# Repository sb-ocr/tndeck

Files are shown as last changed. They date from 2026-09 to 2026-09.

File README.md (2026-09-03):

# TN Deck

Watch the build video ↓

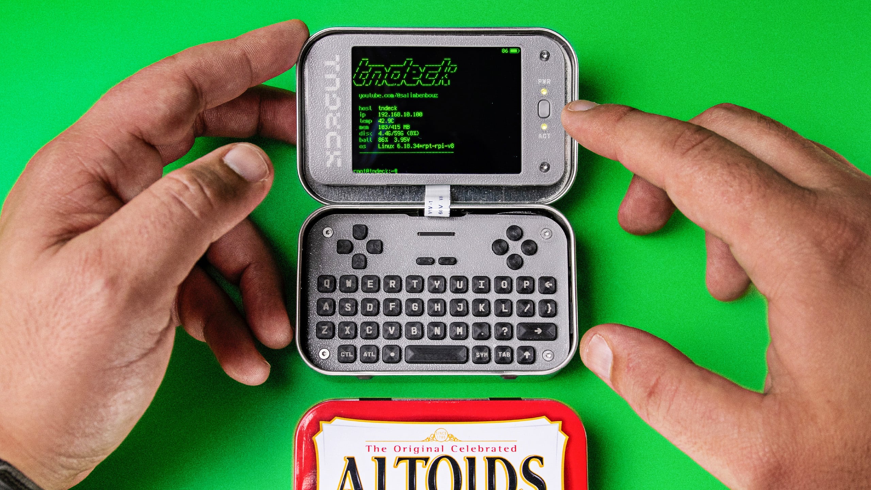
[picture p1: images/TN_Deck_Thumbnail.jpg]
[](https://youtu.be/Ajft97gAxV8)

TN Deck is a tiny handheld cyberdeck built inside an Altoids tin around the Raspberry Pi Compute Module 0. Inspired by projects like the MintyPi and other tin-based builds, it uses custom PCBs, an integrated keyboard, a small display, onboard audio, and battery power.

<sub>⚠️ In these files, R23 was changed to 2.2kΩ to fix the soft-latch issue, and C33 was added to help reset the audio DAC on power-up.</sub>

[][cc-by-nc-sa]

[][cc-by-nc-sa]

[cc-by-nc-sa]: http://creativecommons.org/licenses/by-nc-sa/4.0/
[cc-by-nc-sa-image]: https://licensebuttons.net/l/by-nc-sa/4.0/88x31.png
[cc-by-nc-sa-shield]: https://img.shields.io/badge/License-CC%20BY--NC--SA%204.0-lightgrey.svg

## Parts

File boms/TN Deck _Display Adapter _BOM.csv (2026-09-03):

Reference Designators | Quantity | Package | Value | Vendor Part Number | Vendor | Description | Manufacturer | Manufacturer Part Number | Top/Bottom
 | 1 | Board |  |  |  | Board
C2, C31 | 2 | CAPC1608X85 | 0.1uF | 399-C0603C104K3RACTUCT-ND | Digikey | Capacitor - ANSI |  |  | Top
C30 | 1 | CAPC2012X110 | 10uF | 1292-0805X106K250CT-ND | Digikey | Capacitor - ANSI |  |  | Top
D58, D59 | 2 | LEDC1608X80N_FLAT-G | CHIP-FLAT-G_0603-0.80MM | 732-4980-1-ND | Digikey | Green LED - Generic |  |  | Bottom
J1 | 1 | 2.8_TFT_DISPLAY_ | 62684-502100ALF | 609-1202-1-ND | Digikey |  | Amphenol |  | Top
J2 | 1 | SFV16R-1STE1HLF | SFV16R-1STE1HLF | 609-4313-1-ND | Digikey |  | Amphenol |  | Top
PWR | 1 | KMR2 | SPST-NO_SWITCH_KMR2 | 401-1426-1-ND | Digikey | SPST Switches with NO Configuration | C&K | KMR211G LFS | Bottom
Q1 | 1 | SOT23 | SI2302A | 4518-SI2302ACT-ND | Digikey | N-Channel MOSFET - Generic |  |  | Top
R1, R2, R3, R4 | 4 | RESC1608X60 | 10 | 541-10.0HCT-ND | Digikey | Resistor Fixed - ANSI |  |  | Top
R5, R17 | 2 | RESC1608X60 | 10K | 541-10.0KHCT-ND | Digikey | Resistor Fixed - ANSI |  |  | Top
R9, R10 | 2 | RESC1608X60 | 2.2K | 541-2.20KHCT-ND | Digikey | Resistor Fixed - ANSI |  |  | Top
TP1, TP2, TP3, TP4, TP5, TP6, TP7, TP8, TP9, TP10 | 10 | B1,27 | TPB1,27 |  |  | Test pad |  |  | Top
U$1 | 1 | SOT-23_DIO | APX803S-31SA-7 | APX803S-31SA-7DICT-ND | Digikey |  |  |  | Top
U1 | 1 | RGV16_2P16X2P16 | TSC2046EIRGVRRGV16_2P16X2P16 | 296-46257-1-ND | Digikey |  |  |  | Top

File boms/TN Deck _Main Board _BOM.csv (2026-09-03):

Reference Designators | Quantity | Package | Value | Vendor Part Number | Vendor | Description | Manufacturer | Manufacturer Part Number | Top/Bottom
 | 1 | Board |  |  |  | Board
BAT | 1 | S2B-PH-SM4-TB | S2B-PH-SM4-TB | 455-S2B-PH-SM4-TBCT-ND | Digikey |  | JST |  | Bottom
BOOT, RESET | 2 | KMR2 | SPST-NO_SWITCH_KMR2 | 401-1426-1-ND | Digikey | SPST Switches with NO Configuration | C&K | KMR211G LFS | Bottom
C1, C6, C7, C8, C9, C10, C11, C12, C13, C14, C17, C20, C26, C27, C28, C31 | 16 | CAPC1608X85 | 0.1uF | 399-C0603C104K3RACTUCT-ND | Digikey | Capacitor - ANSI |  |  | Bottom
C2, C3 | 2 | CAPC1608X85 | 15pF | 732-7761-1-ND | Digikey | Capacitor - ANSI |  |  | Bottom
C4, C5, C33 | 2 | CAPC1608X85 | 1uF | 399-C0603C105K4RACTUCT-ND | Digikey | Capacitor - ANSI |  |  | Bottom
C15, C29, C30 | 3 | CAPC2012X110 | 10uF | 1292-0805X106K250CT-ND | Digikey | Capacitor - ANSI |  |  | Bottom
C16, C18, C19, C21, C32 | 5 | CAPC2012X110 | 22uF | 4713-GMC21X5R226M16NTCT-ND | Digikey | Capacitor - ANSI |  |  | Bottom
C22, C23 | 2 | CAPC3216X135 | 100uF/6.3V | 1276-CL31A107MQHNNWECT-ND | Digikey | Capacitor - ANSI |  |  | Bottom
C24, C25 | 2 | CAPC1608X85 | 10nF | 399-C0603C103K4RACTUCT-ND | Digikey | Capacitor - ANSI |  |  | Bottom
D1 | 1 | LEDC1608X80N_FLAT-G | CHIP-FLAT-G_0603-0.80MM | 732-4980-1-ND | Digikey | Green LED - Generic |  |  | Bottom
D2 | 1 | LEDC1608X80N_FLAT-R | CHIP-FLAT-R_0603-0.80MM | 732-4978-1-ND | Digikey | Red LED - Generic |  |  | Bottom
D4, D5 | 2 | SODFL3718X115 | MBR0520LT1G | MBR0520LT1GOSCT-ND | Digikey | Schottky Diode - Popular parts | ON Semiconductor | MBR0520LT1G | Bottom
GPAD_A, GPAD_B, GPAD_D, GPAD_L, GPAD_R, GPAD_U, GPAD_X, GPAD_Y, SELECT, START, SW_?, SW_., SW_}, SW_/, SW_A, SW_ALT, SW_B, SW_BSP, SW_C, SW_CMD, SW_CTL, SW_D, SW_E, SW_ENTER, SW_F, SW_G, SW_H, SW_I, SW_J, SW_K, SW_L, SW_M, SW_N, SW_O, SW_P, SW_Q, SW_R, SW_S, SW_SHFT, SW_SP1, SW_SP2, SW_SYM, SW_T, SW_TAB, SW_U, SW_V, SW_W, SW_X, SW_Y, SW_Z | 50 | TL3315NF100Q | TL3315NF100Q | EG4620CT-ND | Digikey | SWITCH TACTILE SPST-NO 0.05A 15V | E-Switch | TL3315NF100Q | Top
J2 | 1 | 54-00177 | 54-00177 | 839-54-00177CT-ND | Digikey |  | TENSILITY |  | Bottom
J3 | 1 | MSD-4-A | MSD-4-A | 2223-MSD-4-ACT-ND | Digikey |  | CUI Devices |  | Bottom
J4 | 1 | SFV16R-1STE1HLF | SFV16R-1STE1HLF | 609-4313-1-ND | Digikey |  | Amphenol |  | Bottom
J5 | 1 | UJ20-C-H-G-SMT-5-P16-TR | UJ20-C-H-G-SMT-5-P16-TR | 2223-UJ20-C-H-G-SMT-5-P16-TRCT-ND | Digikey |  | Same Sky |  | Bottom
JP1 | 1 | SMT-JUMPER_3_1-NC_TRACE_SILK | JUMPER-SMT_3_1-NC_TRACE_SILK |  |  | Normally closed trace jumper (1 of 2 connections) |  |  | Bottom
JP2 | 1 | SMT-JUMPER_2_NC_TRACE_NO-SILK | JUMPER-SMT_2_NC_TRACE_NO-SILK |  |  | Normally closed trace jumper |  |  | Bottom
L1 | 1 | WE-XHMI_4020 | 1uH | 732-11310-1-ND | Digikey | WE-XHMI SMT Power Inductor |  |  | Bottom
Q1 | 1 | SOT23 | DMP1045UQ-7 | 31-DMP1045UQ-7CT-ND | Digikey | P-Channel MOSFET - Generic |  |  | Bottom
Q2 | 1 | SOT23 | BSS138 | BSS138CT-ND | Digikey | N-Channel MOSFET - Generic |  |  | Bottom
R1, R6, R7, R8, R9, R10, R11, R13, R17, R21, R23, R27, R28 | 13 | RESC1608X60 | 10K | 541-10.0KHCT-ND | Digikey | Resistor Fixed - ANSI |  |  | Bottom
R2, R3 | 2 | RESC1608X60 | 1K | 541-1.00KHCT-ND | Digikey | Resistor Fixed - ANSI |  |  | Bottom
R4, R5 | 2 | RESC1608X60 | 27 | 541-27.0HCT-ND | Digikey | Resistor Fixed - ANSI |  |  | Bottom
R12 | 1 | RESC1608X60 | 13K | 541-13.0KHCT-ND | Digikey | Resistor Fixed - ANSI |  |  | Bottom
R14 | 1 | RESC1608X60 | 600 | 541-604HCT-ND | Digikey | Resistor Fixed - ANSI |  |  | Bottom
R15 | 1 | RESC1608X60 | 732K | 541-732KHCT-ND | Digikey | Resistor Fixed - ANSI |  |  | Bottom
R16, R24 | 2 | RESC1608X60 | 100K | 541-100KHCT-ND | Digikey | Resistor Fixed - ANSI |  |  | Bottom
R19, R20 | 2 | RESC1608X60 | 5.1K | 541-5.10KHCT-ND | Digikey | Resistor Fixed - ANSI |  |  | Bottom
R22 | 1 | RESC1608X60 | 2.2K | 541-2.20KHCT-ND | Digikey | Resistor Fixed - ANSI |  |  | Bottom
R25, R26 | 2 | RESC1608X60 | 200 | 541-200HCT-ND | Digikey | Resistor Fixed - ANSI |  |  | Bottom
SPEAKER | 1 | SPKR_CMS-160925-078S | CMS-160925-078S | 102-4619-ND | Digikey |  | CUI INC |  | Top
TP1, TP2, TP3, TP4, TP5, TP6, TP7, TP8, TP9, TP10, TP11, TP12, TP13, TP14 | 14 | B1,27 | TPB1,27 |  |  | Test pad |  |  | Bottom
U$1 | 1 | CM0 | CM0100000 |  | EDATEC |  |  |  | Bottom
U2 | 1 | QFN40P700X700X90-57N | SC0914(13) | 2648-SC0914(13)CT-ND | Digikey |  | Raspberry Pi |  | Bottom
U3 | 1 | IC_BQ25185DLHR | BQ25185DLHR | 296-BQ25185DLHRCT-ND | Digikey |  | Texas Instruments |  | Bottom
U4 | 1 | DRL0006A | TPS61023DRLRDRL0006A | 296-TPS61023DRLRCT-ND | Digikey |  |  |  | Bottom
U5 | 1 | SOP50P490X110-10N | FSUSB42MUX | FSUSB42MUXCT-ND | Digikey |  | ON Semiconductor |  | Bottom
U6 | 1 | MAX17048G+T10 | MAX17048G+T10 | MAX17048G+T10CT-ND | Digikey |  |  |  | Bottom
U7 | 1 | TLV320DAC3100IRHBR | TLV320DAC3100IRHBR | 296-27216-1-ND | Digikey |  |  |  | Bottom
U8 | 1 | W25Q32JVZPIQ | W25Q32JVZPIQ | 256-W25Q32JVZPIQ-TUBE-ND | Digikey |  |  |  | Bottom
Y1 | 1 | XTAL_ABM8-272-T3 | ABM8-272-T3 | 535-ABM8-272-T3CT-ND | Digikey |  | ABRACON |  | Bottom

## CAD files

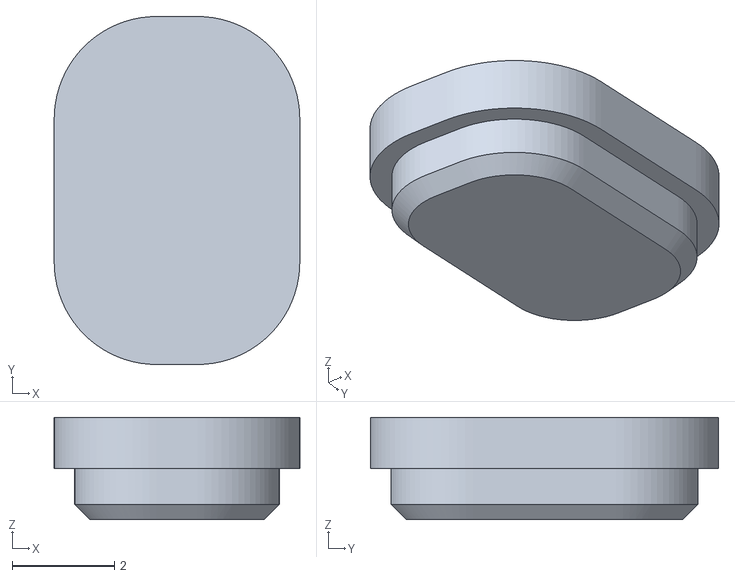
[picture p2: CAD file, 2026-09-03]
enclosure/stl/TN_DECK_DISPLAY_PWR_BUTTON.stl
4.80 x 6.80 x 2.00

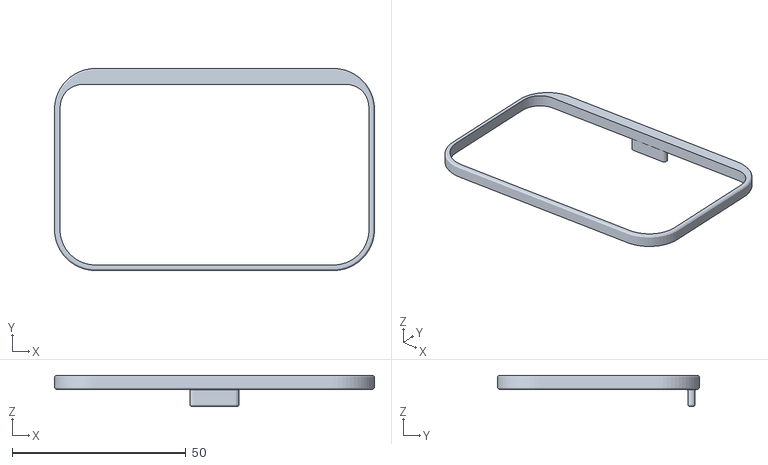
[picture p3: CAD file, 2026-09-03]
enclosure/stl/utils/TN_DECK_DISPLAY_GLUE_SPACER.stl
92.2 x 58.2 x 9.00

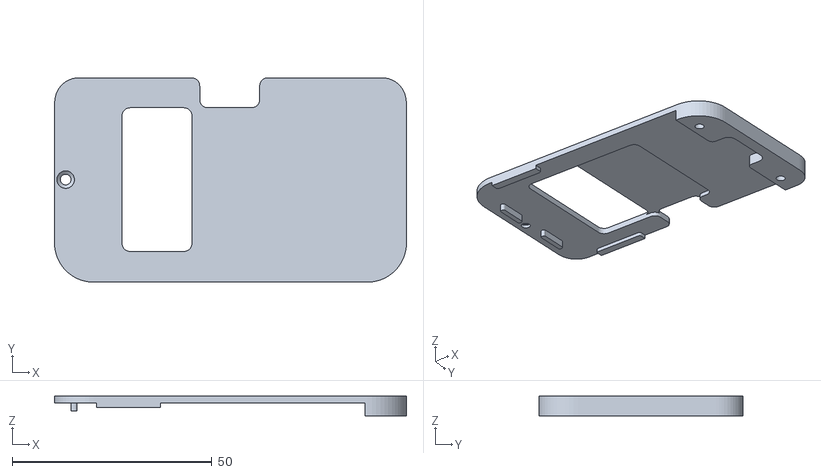
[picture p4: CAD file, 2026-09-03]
enclosure/stl/TN_DECK_DISPLAY_SUPPORT.stl
88.2 x 51.2 x 5.00

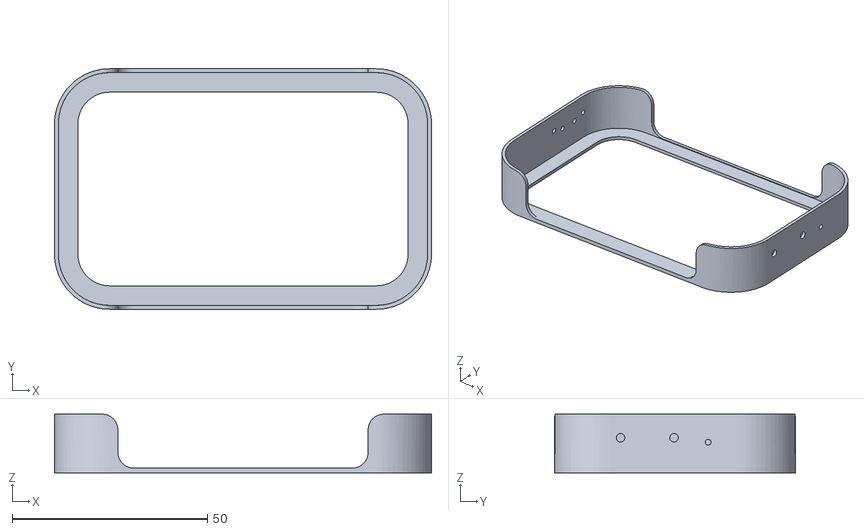
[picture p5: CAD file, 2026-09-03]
enclosure/stl/utils/TN_DECK_TIN_DRILL_JIG.stl
96.5 x 61.5 x 15.0

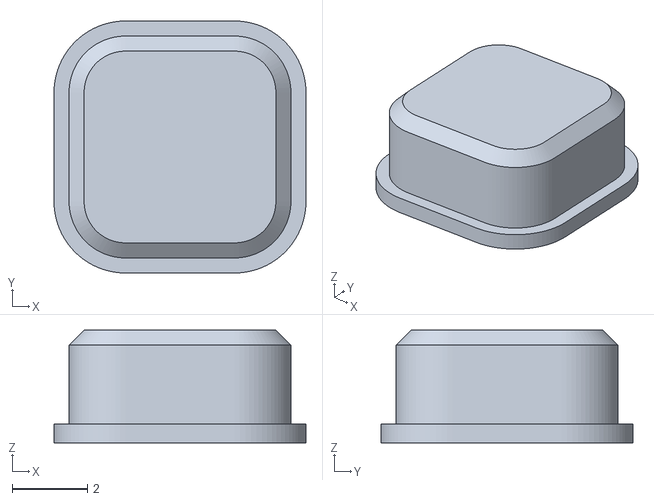
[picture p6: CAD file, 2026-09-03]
enclosure/stl/TN_DECK_KEYBOARD_1U_KEY.stl
6.70 x 6.70 x 3.00

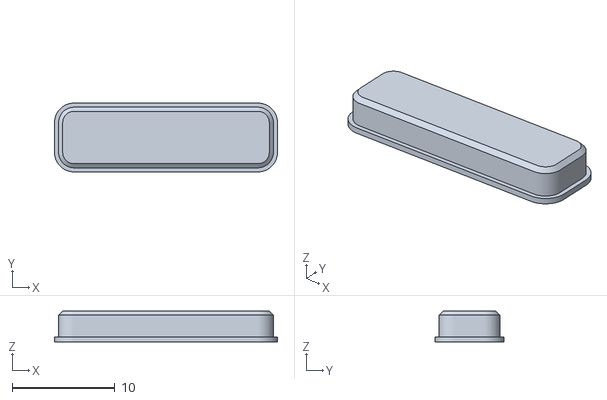
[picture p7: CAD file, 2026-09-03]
enclosure/stl/TN_DECK_KEYBOARD_3U_KEY.stl
21.7 x 6.70 x 3.00

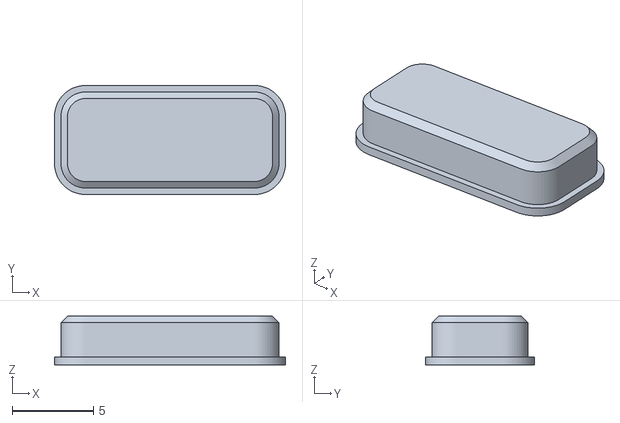
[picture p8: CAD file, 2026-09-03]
enclosure/stl/TN_DECK_KEYBOARD_2U_KEY.stl
14.2 x 6.70 x 3.00

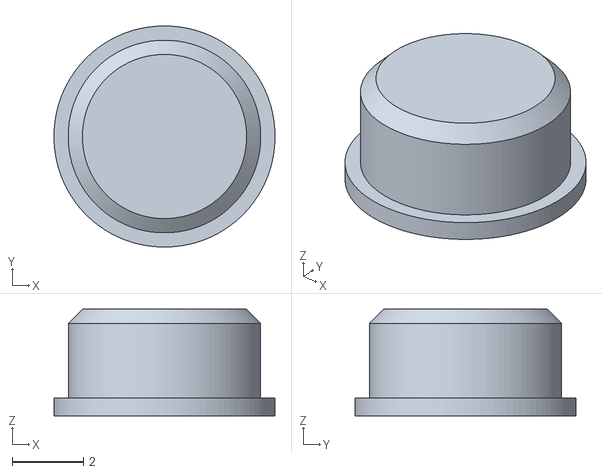
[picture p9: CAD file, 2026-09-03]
enclosure/stl/TN_DECK_KEYBOARD_GPAD_KEY.stl
6.20 x 6.20 x 3.00

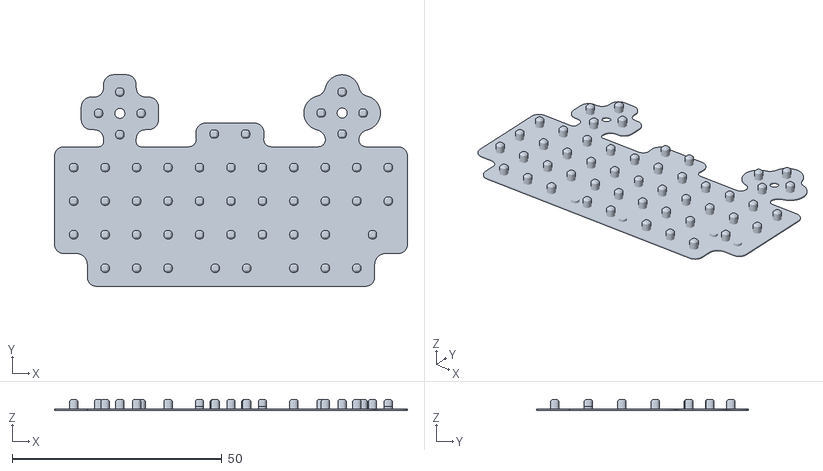
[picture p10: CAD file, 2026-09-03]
enclosure/stl/TN_DECK_KEYBOARD_MEMBRANE.stl
84.2 x 50.5 x 2.70

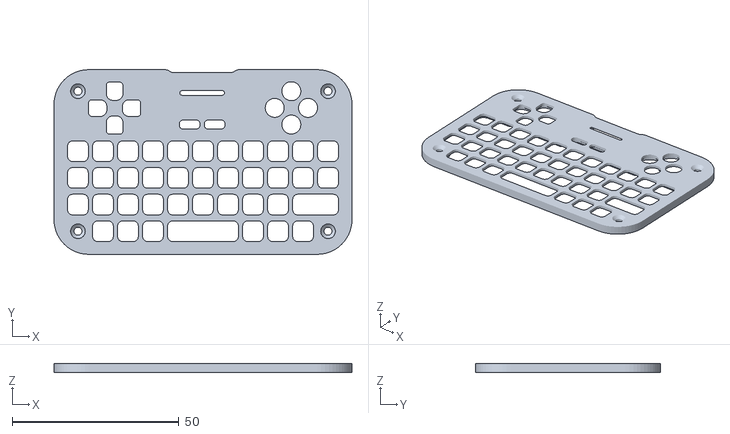
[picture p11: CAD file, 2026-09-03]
enclosure/stl/TN_DECK_KEYBOARD_PLATE.stl
89.4 x 55.4 x 2.80

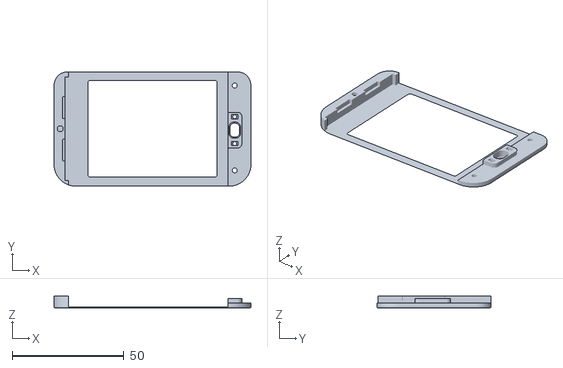
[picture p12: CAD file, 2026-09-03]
enclosure/stl/TN_DECK_DISPLAY_BEZEL.stl
88.2 x 51.2 x 5.40

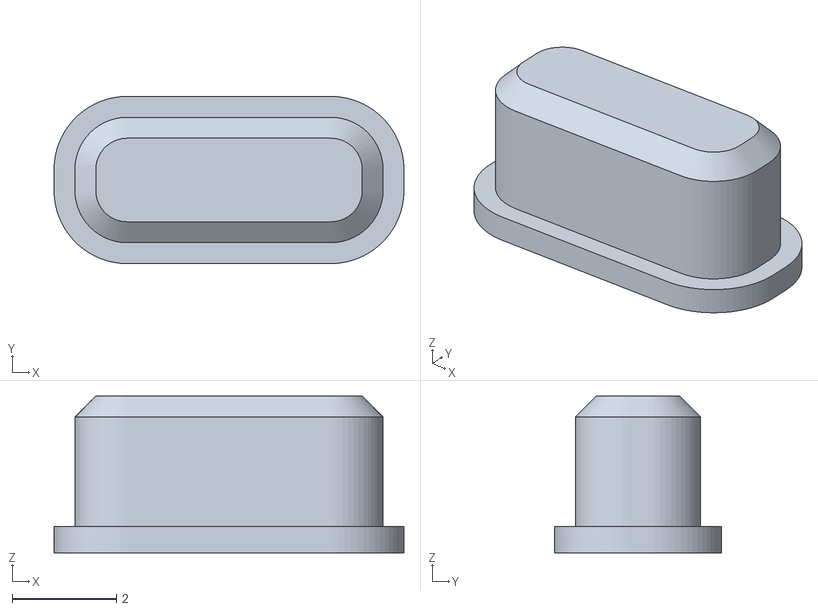
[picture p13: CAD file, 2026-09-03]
enclosure/stl/TN_DECK_KEYBOARD_SL_KEY.stl
6.70 x 3.20 x 3.00

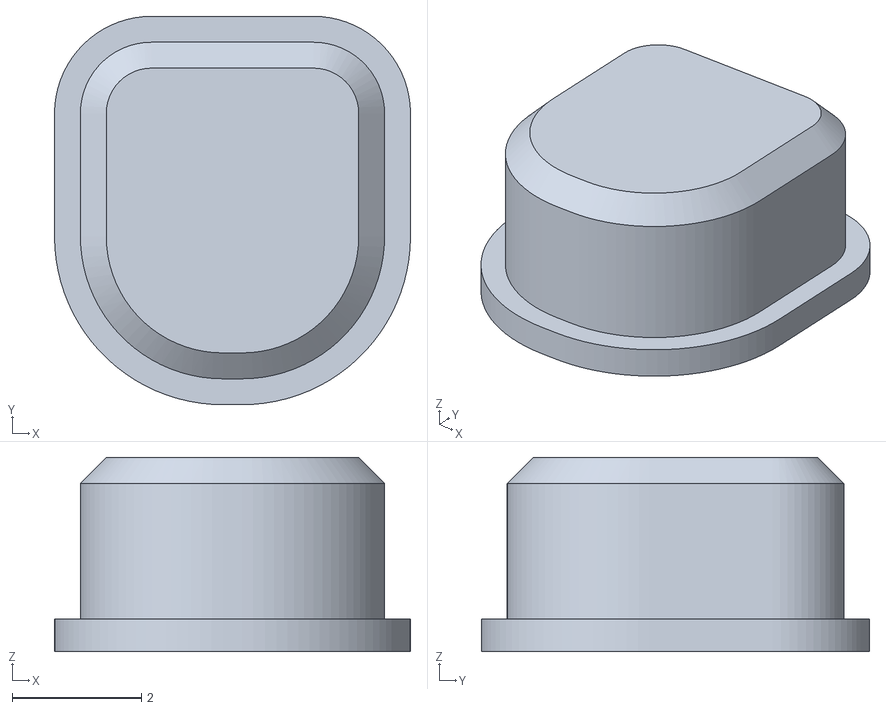
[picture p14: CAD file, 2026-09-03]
enclosure/stl/TN_DECK_KEYBOARD_DPAD_KEY.stl
5.50 x 6.00 x 3.00

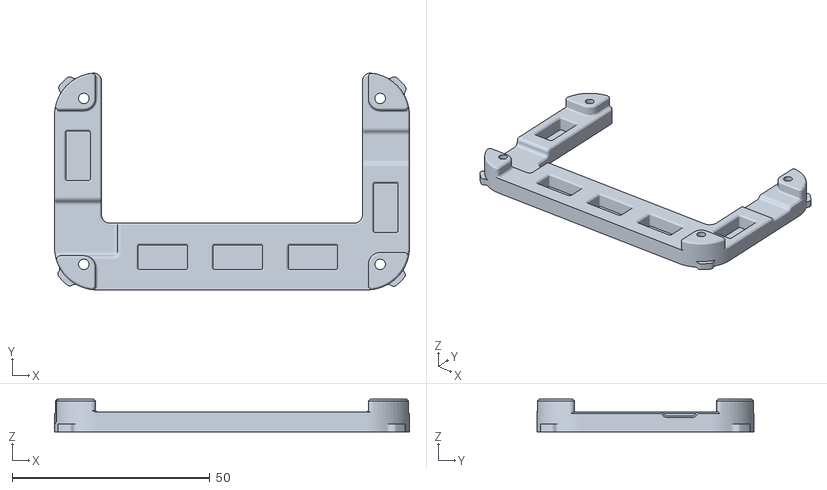
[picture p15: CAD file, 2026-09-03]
enclosure/stl/TN_DECK_BOTTOM_SUPPORT.stl
89.8 x 54.9 x 8.27

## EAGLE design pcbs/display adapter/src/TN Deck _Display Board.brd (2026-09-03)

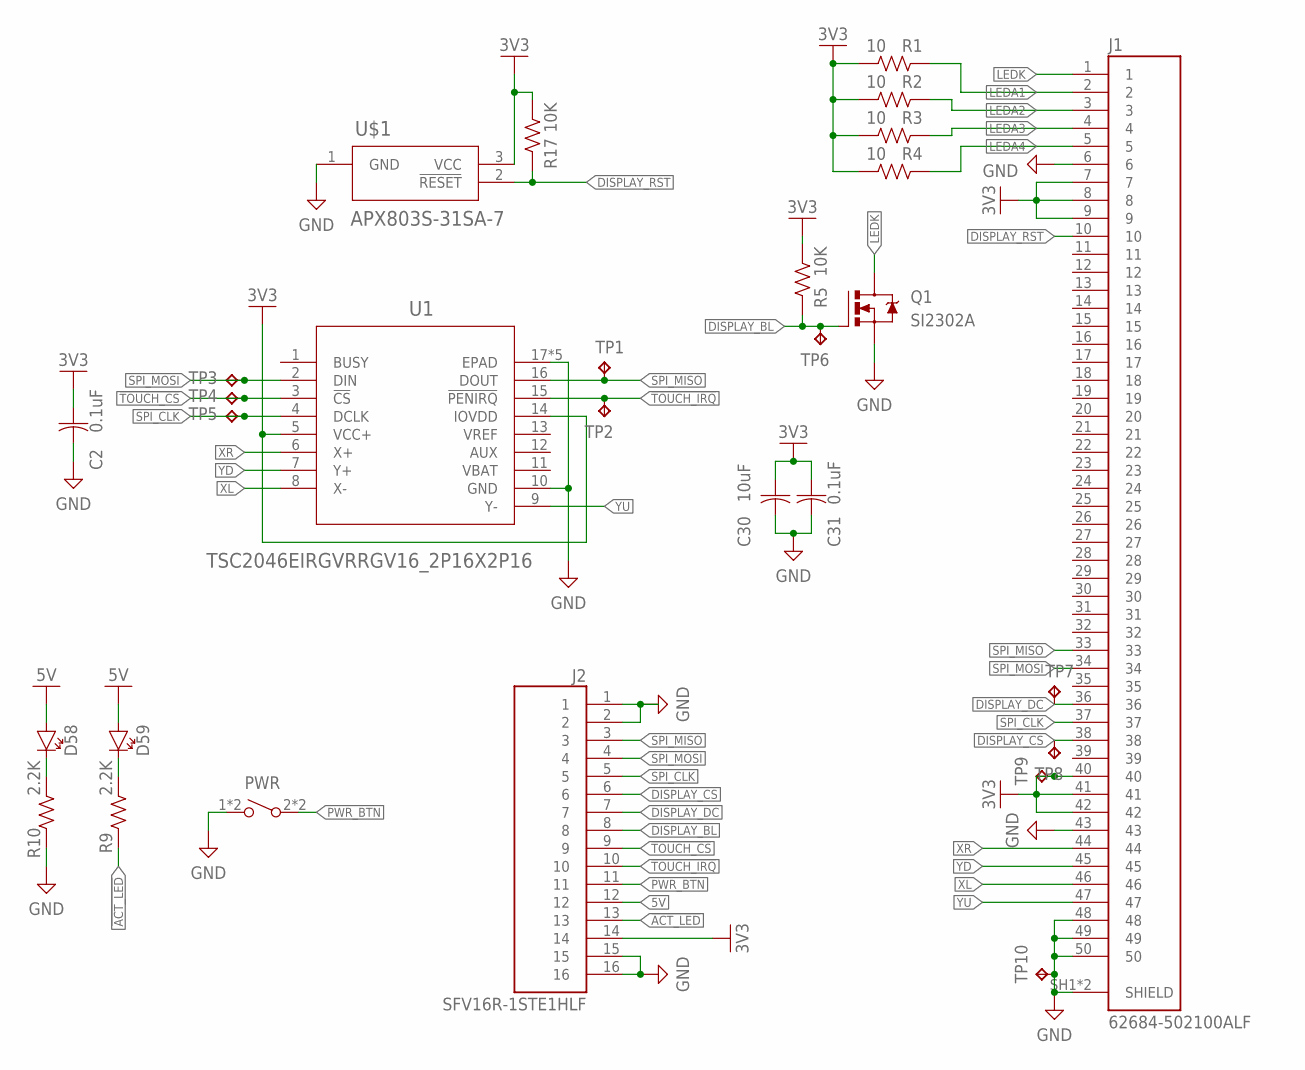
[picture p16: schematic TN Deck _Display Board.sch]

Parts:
C2, C31: 0.1uF; CAPC1608X85
C30: 10uF; CAPC2012X110
D58, D59: CHIP-FLAT-G_0603-0.80MM; LEDC1608X80N_FLAT-G
J1: 62684-502100ALF; AMPHENOL_62684-502100ALF
J2: SFV16R-1STE1HLF; AMPHENOL_SFV16R-1STE1HLF
PWR: SPST-NO_SWITCH_KMR2; KMR2
Q1: SI2302A; SOT23
R1, R2, R3, R4: 10; RESC1608X60
R5, R17: 10K; RESC1608X60
R9, R10: 2.2K; RESC1608X60
TP1, TP2, TP3, TP4, TP5, TP6, TP7, TP8, TP9, TP10: TPB1,27; B1,27
U1: TSC2046EIRGVRRGV16_2P16X2P16; RGV16_2P16X2P16
U$1: APX803S-31SA-7; SOT-23_DIO

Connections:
3V3: C2.1, C30.1, C31.1, J1.7, J1.8, J1.9, J1.40, J1.41, J1.42, J2.14, R1.2, R2.2, R3.2, R4.2, R5.2, R17.2, TP9.TP, U1.5 (VCC+), U1.14 (IOVDD), U$1.3 (VCC)
5V: D58.A, D59.A, J2.12
!ACT_LED: J2.13, R9.1
!TOUCH_CS: J2.9, TP4.TP, U1.3 (!CS)
!TOUCH_IRQ: J2.10, TP2.TP, U1.15 (!PENIRQ)
DISPLAY_BL: J2.8, Q1.1 (G), R5.1, TP6.TP
DISPLAY_CS: J1.38, J2.6, TP8.TP
DISPLAY_DC: J1.36, J2.7, TP7.TP
DISPLAY_RST: J1.10, R17.1, U$1.2 (!RESET)
GND: C2.2, C30.2, C31.2, J1.6, J1.43, J1.48, J1.49, J1.50, J1.SH1 (SHIELD), J1.SH2 (SHIELD), J2.1, J2.2, J2.15, J2.16, PWR.1, PWR.4 (1), Q1.2 (S), R10.1, TP10.TP, U1.10 (GND), U1.17 (EPAD), U1.V (EPAD), U1.V_1 (EPAD), U1.V_2 (EPAD), U1.V_3 (EPAD), U$1.1 (GND)
LEDA1: J1.2, R1.1
LEDA2: J1.3, R2.1
LEDA3: J1.4, R3.1
LEDA4: J1.5, R4.1
LEDK: J1.1, Q1.3 (D)
unnamed: D59.C, R9.2
unnamed: D58.C, R10.2
PWR_BTN: J2.11, PWR.2, PWR.3 (2)
SPI_CLK: J1.37, J2.5, TP5.TP, U1.4 (DCLK)
SPI_MISO: J1.33, J2.3, TP1.TP, U1.16 (DOUT)
SPI_MOSI: J1.34, J2.4, TP3.TP, U1.2 (DIN)
VREF: U1.13 (VREF)
XL: J1.46, U1.8 (X-)
XR: J1.44, U1.6 (X+)
YD: J1.45, U1.7 (Y+)
YU: J1.47, U1.9 (Y-)

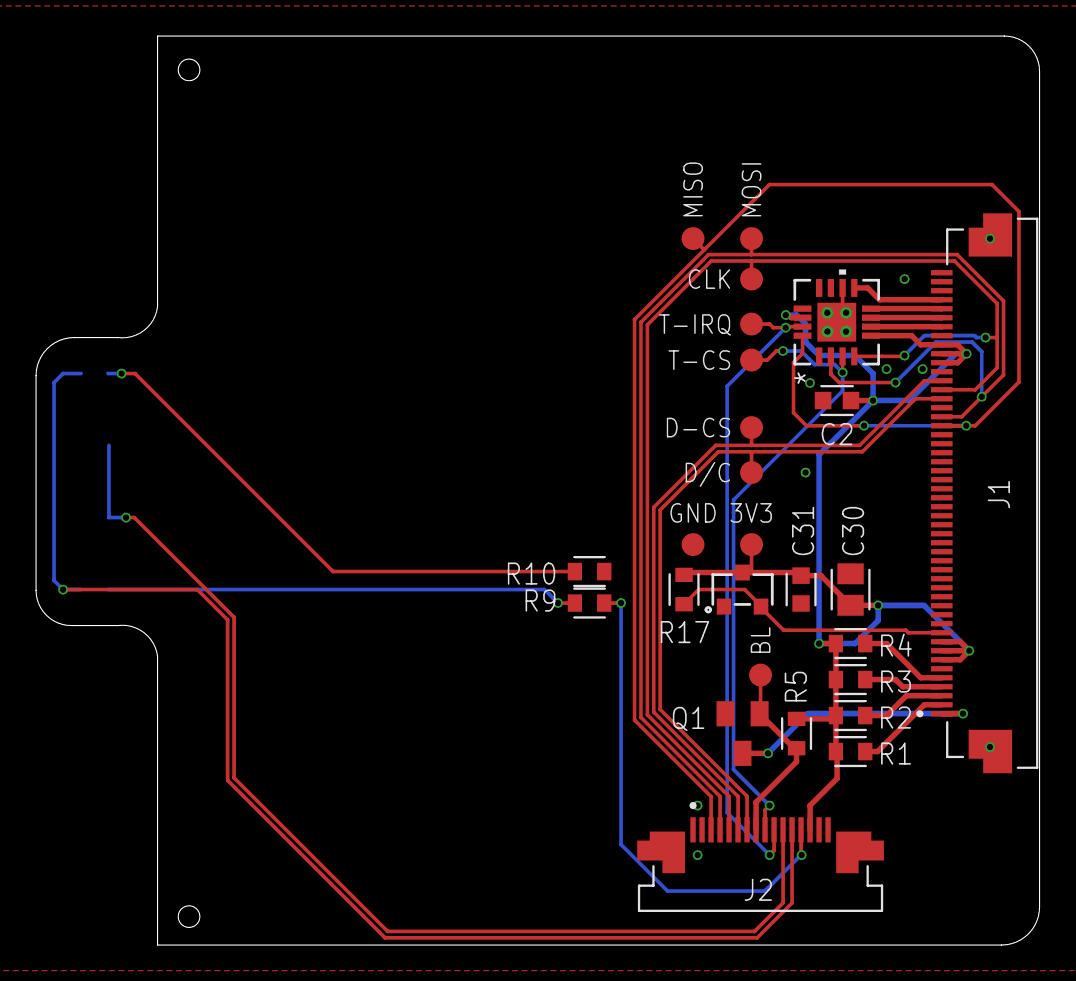
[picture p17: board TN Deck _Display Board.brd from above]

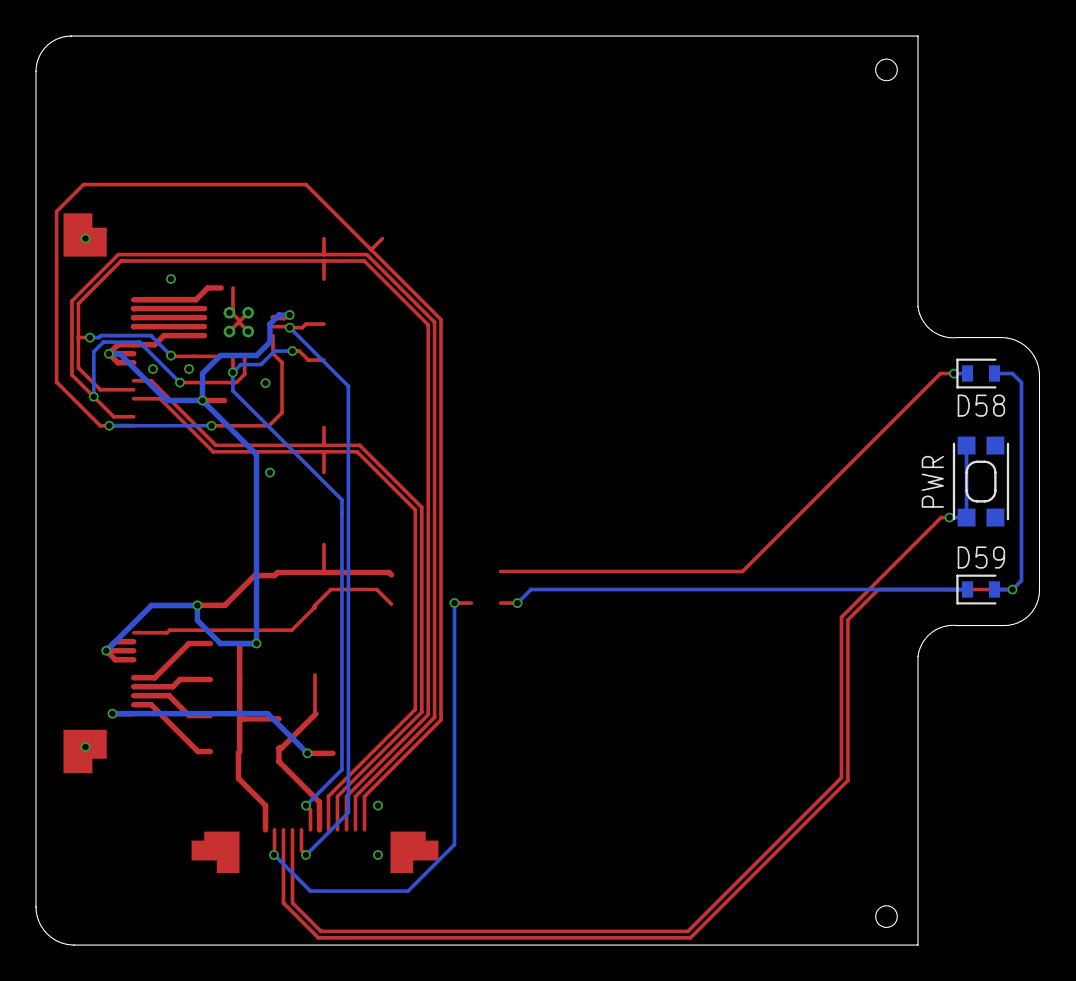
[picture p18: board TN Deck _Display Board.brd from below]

Board: 2 copper layers, 55.7 x 50.5 mm, 29 parts (3 on the bottom side), 25 nets.

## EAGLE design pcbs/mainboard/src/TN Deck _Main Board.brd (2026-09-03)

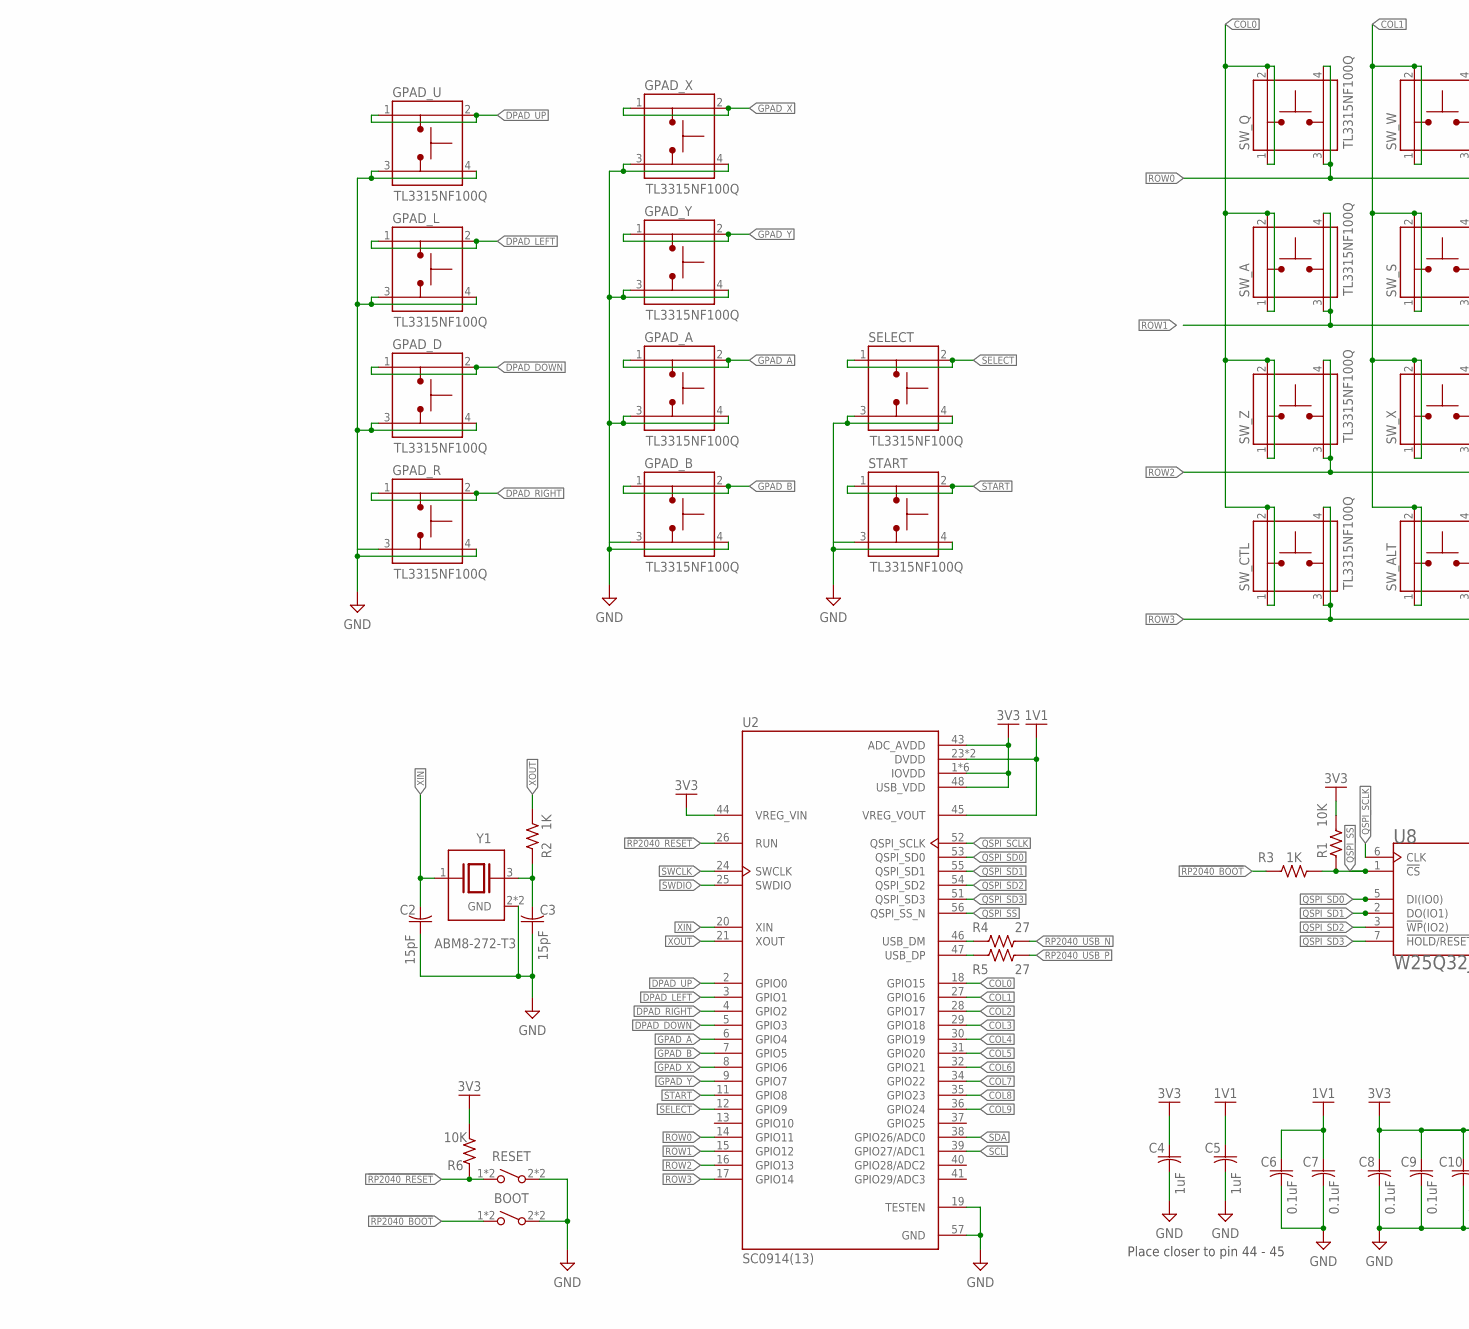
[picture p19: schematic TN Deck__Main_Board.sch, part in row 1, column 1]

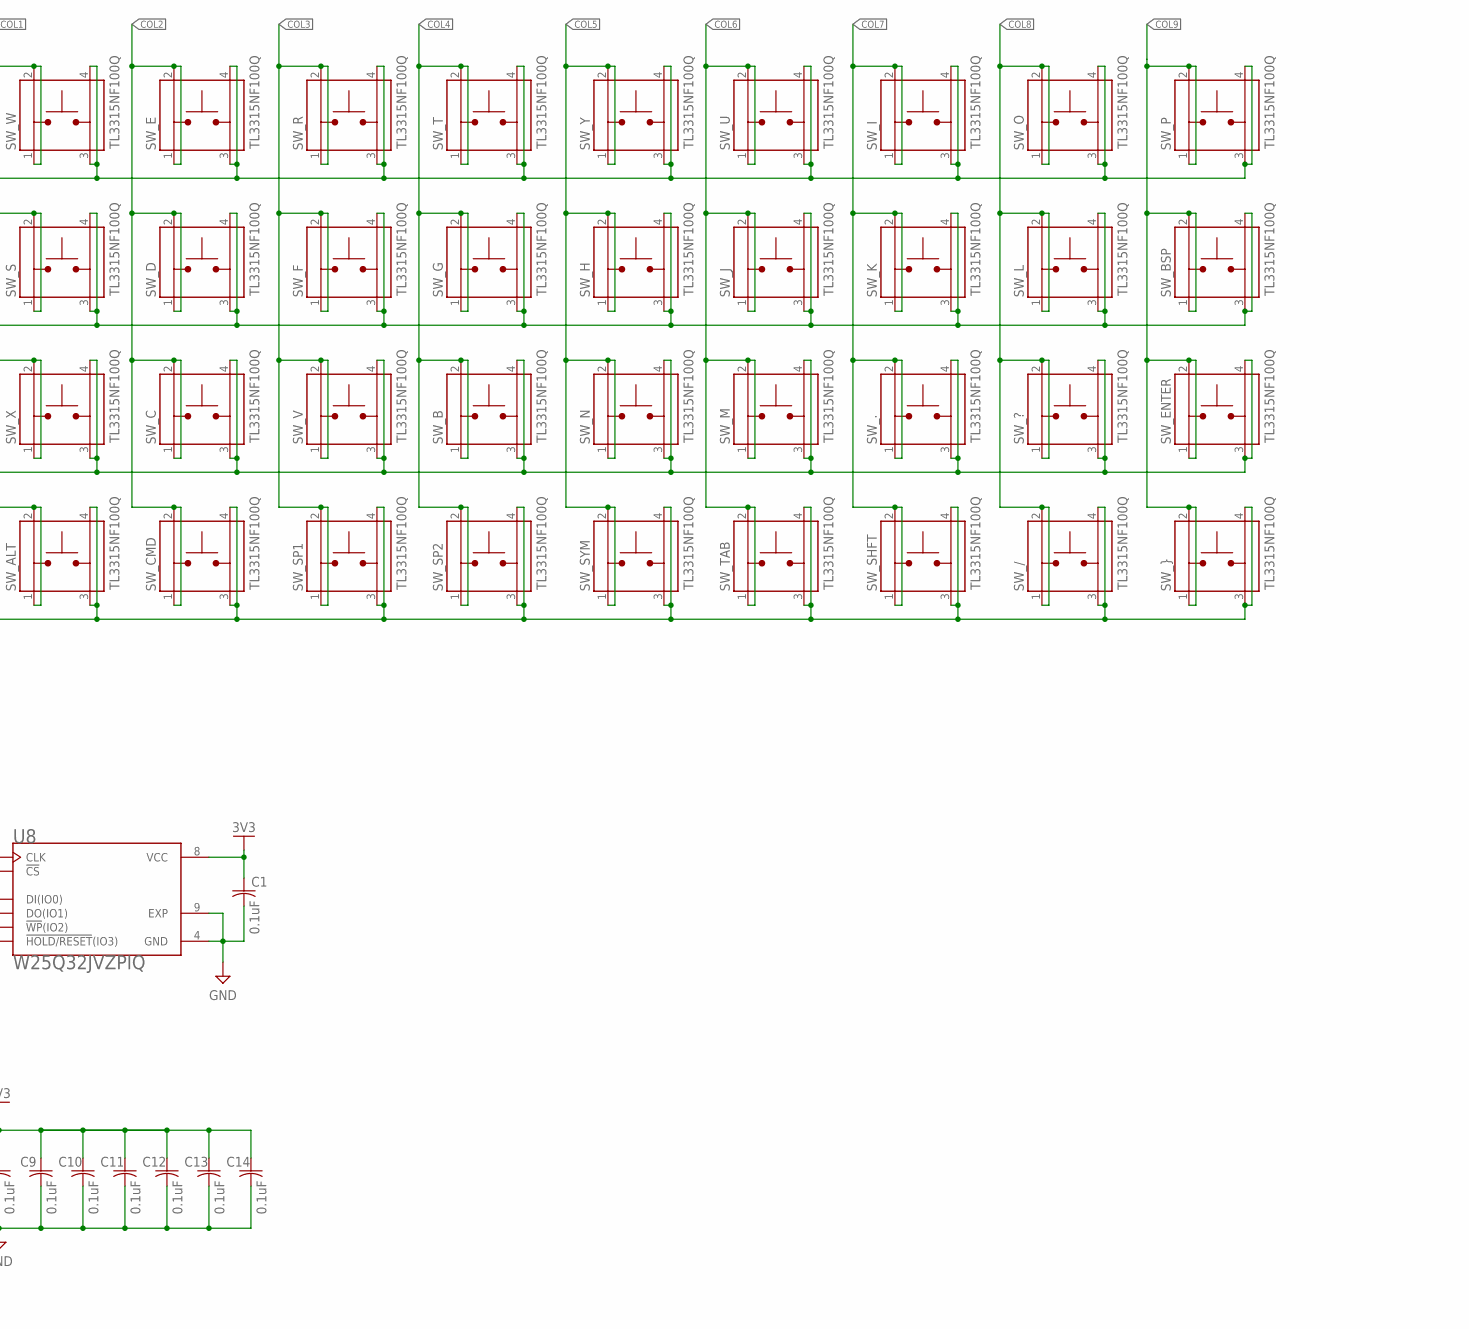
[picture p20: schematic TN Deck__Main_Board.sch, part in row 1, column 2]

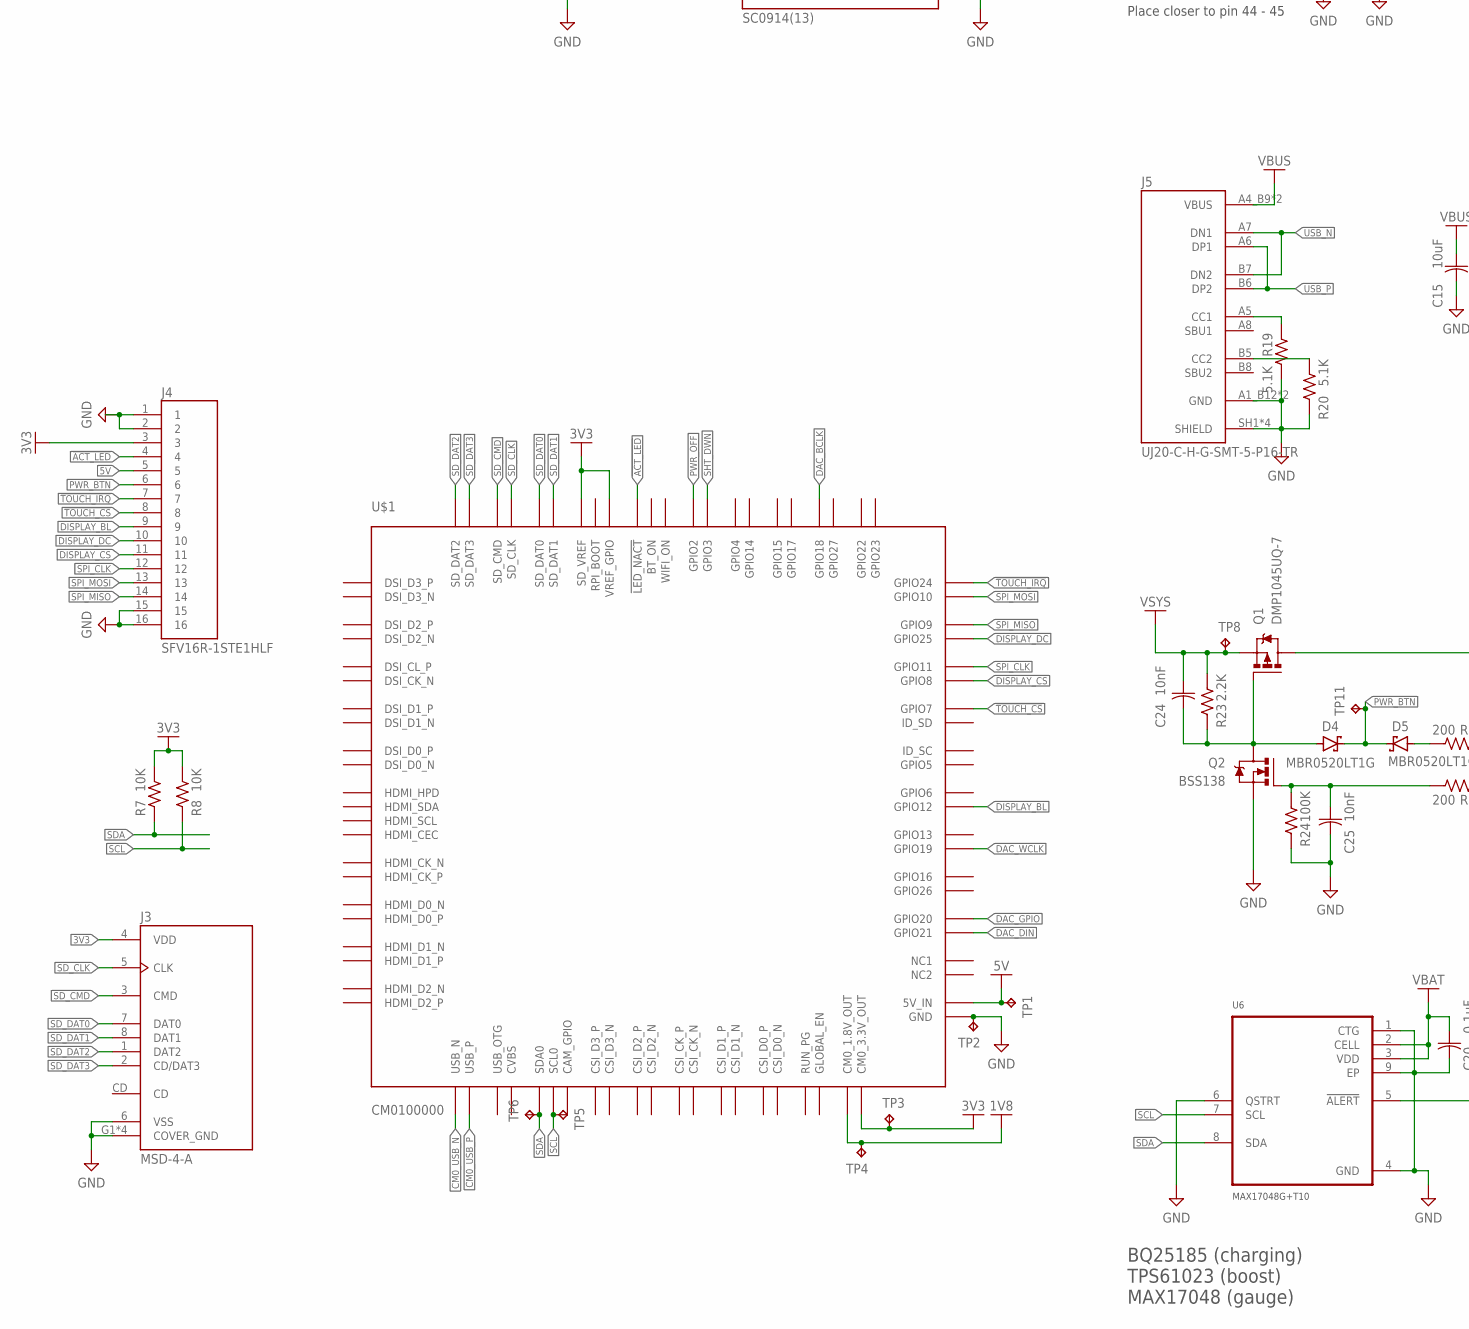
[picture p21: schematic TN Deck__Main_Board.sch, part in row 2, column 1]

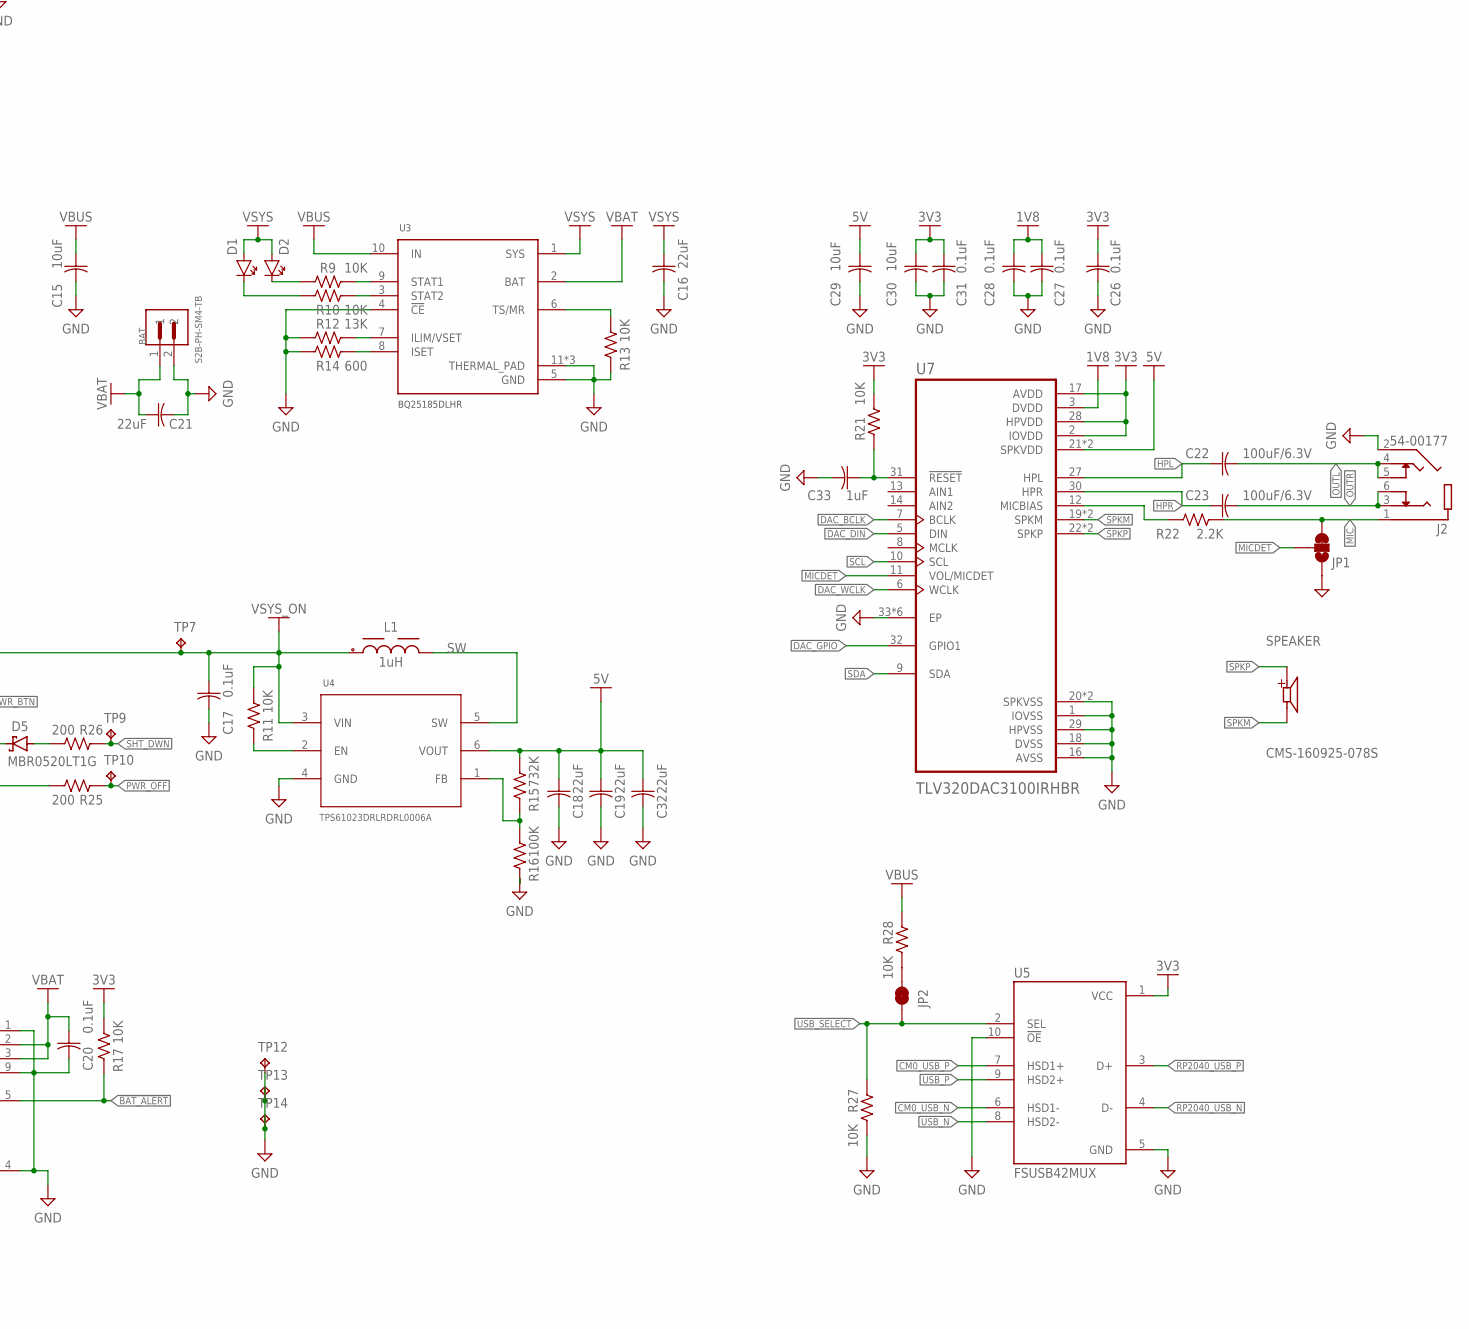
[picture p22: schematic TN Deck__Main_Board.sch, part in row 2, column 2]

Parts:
BAT: S2B-PH-SM4-TB; JST_S2B-PH-SM4-TB
BOOT: SPST-NO_SWITCH_KMR2; KMR2
C1, C6, C7, C8, C9, C10, C11, C12, C13, C14, C17, C20, C26, C27, C28, C31: 0.1uF; CAPC1608X85
C2, C3: 15pF; CAPC1608X85
C4, C5, C33: 1uF; CAPC1608X85
C15, C29, C30: 10uF; CAPC2012X110
C16, C18, C19, C21, C32: 22uF; CAPC2012X110
C22, C23: 100uF/6.3V; CAPC3216X135
C24, C25: 10nF; CAPC1608X85
D1: CHIP-FLAT-G_0603-0.80MM; LEDC1608X80N_FLAT-G
D2: CHIP-FLAT-R_0603-0.80MM; LEDC1608X80N_FLAT-R
D4, D5: MBR0520LT1G; SODFL3718X115
GPAD_A: TL3315NF100Q
GPAD_B: TL3315NF100Q
GPAD_D: TL3315NF100Q
GPAD_L: TL3315NF100Q
GPAD_R: TL3315NF100Q
GPAD_U: TL3315NF100Q
GPAD_X: TL3315NF100Q
GPAD_Y: TL3315NF100Q
J2: 54-00177; TENSILITY_54-00177
J3: MSD-4-A; CUI_MSD-4-A
J4: SFV16R-1STE1HLF; AMPHENOL_SFV16R-1STE1HLF
J5: UJ20-C-H-G-SMT-5-P16-TR; SAMESKY_UJ20-C-H-G-SMT-5-P16-TR
JP1: JUMPER-SMT_3_1-NC_TRACE_SILK; SMT-JUMPER_3_1-NC_TRACE_SILK
JP2: JUMPER-SMT_2_NC_TRACE_NO-SILK; SMT-JUMPER_2_NC_TRACE_NO-SILK
L1: 1uH; WE-XHMI_4020
Q1: DMP1045UQ-7; SOT23
Q2: BSS138; SOT23
R1, R6, R7, R8, R9, R10, R11, R13, R17, R21, R27, R28: 10K; RESC1608X60
R2, R3: 1K; RESC1608X60
R4, R5: 27; RESC1608X60
R12: 13K; RESC1608X60
R14: 600; RESC1608X60
R15: 732K; RESC1608X60
R16, R24: 100K; RESC1608X60
R19, R20: 5.1K; RESC1608X60
R22, R23: 2.2K; RESC1608X60
R25, R26: 200; RESC1608X60
RESET: SPST-NO_SWITCH_KMR2; KMR2
SELECT: TL3315NF100Q
SPEAKER: CMS-160925-078S; SPKR_CMS-160925-078S
START: TL3315NF100Q
SW_.: TL3315NF100Q
SW_/: TL3315NF100Q
SW_?: TL3315NF100Q
SW_A: TL3315NF100Q
SW_ALT: TL3315NF100Q
SW_B: TL3315NF100Q
SW_BSP: TL3315NF100Q
SW_C: TL3315NF100Q
SW_CMD: TL3315NF100Q
SW_CTL: TL3315NF100Q
SW_D: TL3315NF100Q
SW_E: TL3315NF100Q
SW_ENTER: TL3315NF100Q
SW_F: TL3315NF100Q
SW_G: TL3315NF100Q
SW_H: TL3315NF100Q
SW_I: TL3315NF100Q
SW_J: TL3315NF100Q
SW_K: TL3315NF100Q
SW_L: TL3315NF100Q
SW_M: TL3315NF100Q
SW_N: TL3315NF100Q
SW_O: TL3315NF100Q
SW_P: TL3315NF100Q
SW_Q: TL3315NF100Q
SW_R: TL3315NF100Q
SW_S: TL3315NF100Q
SW_SHFT: TL3315NF100Q
SW_SP1, SW_SP2: TL3315NF100Q
SW_SYM: TL3315NF100Q
SW_T: TL3315NF100Q
SW_TAB: TL3315NF100Q
SW_U: TL3315NF100Q
SW_V: TL3315NF100Q
SW_W: TL3315NF100Q
SW_X: TL3315NF100Q
SW_Y: TL3315NF100Q
SW_Z: TL3315NF100Q
SW_}: TL3315NF100Q
TP1, TP2, TP3, TP4, TP5, TP6, TP7, TP8, TP9, TP10, TP11, TP12, TP13, TP14: TPB1,27; B1,27
U2: SC0914(13); QFN40P700X700X90-57N
U3: BQ25185DLHR; IC_BQ25185DLHR
U4: TPS61023DRLRDRL0006A; DRL0006A
U5: FSUSB42MUX; SOP50P490X110-10N
U6: MAX17048G+T10; SON50P200X200X80-9N
U7: TLV320DAC3100IRHBR; IC_ADS125H01IRHBT
U8: W25Q32JVZPIQ; SON127P600X500X80-9N
U$1: CM0100000; CM0
Y1: ABM8-272-T3; XTAL_ABM8-272-T3

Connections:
1V1: C5.1, C6.1, C7.1, U2.23 (DVDD), U2.45 (VREG_VOUT), U2.50 (DVDD)
1V8: C27.1, C28.1, TP4.TP, U7.3 (DVDD), U$1.P$64 (CM0_1.8V_OUT), U$1.P$65 (CM0_1.8V_OUT)
3V3: C1.1, C4.1, C8.1, C9.1, C10.1, C11.1, C12.1, C13.1, C14.1, C26.1, C30.1, C31.1, J3.4 (VDD), J4.3, R1.2, R6.2, R7.2, R8.2, R17.2, R21.2, TP3.TP, U2.1 (IOVDD), U2.10 (IOVDD), U2.22 (IOVDD), U2.33 (IOVDD), U2.42 (IOVDD), U2.43 (ADC_AVDD), U2.44 (VREG_VIN), U2.48 (USB_VDD), U2.49 (IOVDD), U5.1 (VCC), U7.2 (IOVDD), U7.17 (AVDD), U7.28 (HPVDD), U8.8 (VCC), U$1.P$41 (CM0_3.3V_OUT), U$1.P$119 (CM0_3.3V_OUT), U$1.P$120 (VREF_GPIO), U$1.P$122 (SD_VREF)
5V: C18.1, C19.1, C29.1, C32.1, J4.5, R15.2, TP1.TP, U4.6 (VOUT), U7.21 (SPKVDD), U7.24 (SPKVDD), U$1.P$67 (5V_IN), U$1.P$68 (5V_IN)
!ACT_LED: J4.4, U$1.P$118 (!LED_NACT)
!BAT_ALERT: R17.1, U6.5 (!ALERT)
!RP2040_BOOT: BOOT.1, BOOT.4 (1), R3.1
!RP2040_RESET: R6.1, RESET.1, RESET.4 (1), U2.26 (RUN)
!TOUCH_CS: J4.8, U$1.P$89 (GPIO7)
!TOUCH_IRQ: J4.7, U$1.P$98 (GPIO24)
CM0_USB_N: U5.6 (HSD1-), U$1.P$35 (USB_N)
CM0_USB_P: U5.7 (HSD1+), U$1.P$36 (USB_P)
COL0: SW_A.1, SW_A.2, SW_CTL.1, SW_CTL.2, SW_Q.1, SW_Q.2, SW_Z.1, SW_Z.2, U2.18 (GPIO15)
COL1: SW_ALT.1, SW_ALT.2, SW_S.1, SW_S.2, SW_W.1, SW_W.2, SW_X.1, SW_X.2, U2.27 (GPIO16)
COL2: SW_C.1, SW_C.2, SW_CMD.1, SW_CMD.2, SW_D.1, SW_D.2, SW_E.1, SW_E.2, U2.28 (GPIO17)
COL3: SW_F.1, SW_F.2, SW_R.1, SW_R.2, SW_SP1.1, SW_SP1.2, SW_V.1, SW_V.2, U2.29 (GPIO18)
COL4: SW_B.1, SW_B.2, SW_G.1, SW_G.2, SW_SP2.1, SW_SP2.2, SW_T.1, SW_T.2, U2.30 (GPIO19)
COL5: SW_H.1, SW_H.2, SW_N.1, SW_N.2, SW_SYM.1, SW_SYM.2, SW_Y.1, SW_Y.2, U2.31 (GPIO20)
COL6: SW_J.1, SW_J.2, SW_M.1, SW_M.2, SW_TAB.1, SW_TAB.2, SW_U.1, SW_U.2, U2.32 (GPIO21)
COL7: SW_..1, SW_..2, SW_I.1, SW_I.2, SW_K.1, SW_K.2, SW_SHFT.1, SW_SHFT.2, U2.34 (GPIO22)
COL8: SW_/.1, SW_/.2, SW_?.1, SW_?.2, SW_L.1, SW_L.2, SW_O.1, SW_O.2, U2.35 (GPIO23)
COL9: SW_BSP.1, SW_BSP.2, SW_ENTER.1, SW_ENTER.2, SW_P.1, SW_P.2, SW_}.1, SW_}.2, U2.36 (GPIO24)
DAC_BCLK: U7.7 (BCLK), U$1.P$105 (GPIO18)
DAC_DIN: U7.5 (DIN), U$1.P$73 (GPIO21)
DAC_GPIO: U7.32 (GPIO1), U$1.P$74 (GPIO20)
DAC_WCLK: U7.6 (WCLK), U$1.P$79 (GPIO19)
DISPLAY_BL: J4.9, U$1.P$82 (GPIO12)
DISPLAY_CS: J4.11, U$1.P$91 (GPIO8)
DISPLAY_DC: J4.10, U$1.P$94 (GPIO25)
DPAD_DOWN: GPAD_D.1, GPAD_D.2, U2.5 (GPIO3)
DPAD_LEFT: GPAD_L.1, GPAD_L.2, U2.3 (GPIO1)
DPAD_RIGHT: GPAD_R.1, GPAD_R.2, U2.4 (GPIO2)
DPAD_UP: GPAD_U.1, GPAD_U.2, U2.2 (GPIO0)
GND: BAT.2, BOOT.2, BOOT.3 (2), C1.2, C2.1, C3.1, C4.2, C5.2, C6.2, C7.2, C8.2, C9.2, C10.2, C11.2, C12.2, C13.2, C14.2, C15.2, C16.2, C17.2, C18.2, C19.2, C20.2, C21.2, C25.2, C26.2, C27.2, C28.2, C29.2, C30.2, C31.2, C32.2, C33.2, GPAD_A.3, GPAD_A.4, GPAD_B.3, GPAD_B.4, GPAD_D.3, GPAD_D.4, GPAD_L.3, GPAD_L.4, GPAD_R.3, GPAD_R.4, GPAD_U.3, GPAD_U.4, GPAD_X.3, GPAD_X.4, GPAD_Y.3, GPAD_Y.4, J2.2, J3.6 (VSS), J3.G1 (COVER_GND), J3.G2 (COVER_GND), J3.G3 (COVER_GND), J3.G4 (COVER_GND), J4.1, J4.2, J4.15, J4.16, J5.A1_B12 (GND), J5.A12_B1 (GND), J5.SH1 (SHIELD), J5.SH2 (SHIELD), J5.SH3 (SHIELD), J5.SH4 (SHIELD), JP1.1, Q2.2 (S), R12.1, R13.1, R14.1, R16.1, R19.2, R20.1, R24.1, R27.2, RESET.2, RESET.3 (2), SELECT.3, SELECT.4, START.3, START.4, TP2.TP, TP12.TP, TP13.TP, TP14.TP, U2.19 (TESTEN), U2.57 (GND), U3.4 (!CE), U3.5 (GND), U3.11 (THERMAL_PAD), U3.12 (THERMAL_PAD), U3.13 (THERMAL_PAD), U4.4 (GND), U5.5 (GND), U5.10 (!OE), U6.1 (CTG), U6.4 (GND), U6.6 (QSTRT), U6.9 (EP), U7.1 (IOVSS), U7.16 (AVSS), U7.18 (DVSS), U7.20 (SPKVSS), U7.25 (SPKVSS), U7.29 (HPVSS), U7.33 (EP), U7.34 (EP), U7.35 (EP), U7.36 (EP), U7.37 (EP), U7.38 (EP), U8.4 (GND), U8.9 (EXP), U$1.P$1 (GND), U$1.P$4 (GND), U$1.P$7 (GND), U$1.P$10 (GND), U$1.P$13 (GND), U$1.P$16 (GND), U$1.P$21 (GND), U$1.P$24 (GND), U$1.P$27 (GND), U$1.P$30 (GND), U$1.P$33 (GND), U$1.P$34 (GND), U$1.P$37 (GND), U$1.P$40 (GND), U$1.P$45 (GND), U$1.P$48 (GND), U$1.P$51 (GND), U$1.P$54 (GND), U$1.P$57 (GND), U$1.P$60 (GND), U$1.P$63 (GND), U$1.P$66 (GND), U$1.P$69 (GND), U$1.P$72 (GND), U$1.P$75 (GND), U$1.P$78 (GND), U$1.P$81 (GND), U$1.P$84 (GND), U$1.P$87 (GND), U$1.P$90 (GND), U$1.P$93 (GND), U$1.P$96 (GND), U$1.P$99 (GND), U$1.P$100 (GND), U$1.P$103 (GND), U$1.P$106 (GND), U$1.P$109 (GND), U$1.P$112 (GND), U$1.P$115 (GND), U$1.P$123 (GND), U$1.P$126 (GND), U$1.P$129 (GND), U$1.P$132 (GND), Y1.2 (GND), Y1.4 (GND)
GPAD_A: GPAD_A.1, GPAD_A.2, U2.6 (GPIO4)
GPAD_B: GPAD_B.1, GPAD_B.2, U2.7 (GPIO5)
GPAD_X: GPAD_X.1, GPAD_X.2, U2.8 (GPIO6)
GPAD_Y: GPAD_Y.1, GPAD_Y.2, U2.9 (GPIO7)
HPL: C22.1, U7.27 (HPL)
HPR: C23.1, U7.30 (HPR)
MIC: J2.1, JP1.3, R22.2
MICBIAS: R22.1, U7.12 (MICBIAS)
MICDET: JP1.2, U7.11 (VOL/MICDET)
unnamed: R12.2, U3.7 (ILIM/VSET)
unnamed: R14.2, U3.8 (ISET)
unnamed: R13.2, U3.6 (TS/MR)
unnamed: R9.2, U3.9 (STAT1)
unnamed: D2.C, R9.1
unnamed: R10.2, U3.3 (STAT2)
unnamed: D1.C, R10.1
unnamed: R11.1, U4.2 (EN)
unnamed: C3.2, R2.1, Y1.3
unnamed: J5.A5 (CC1), R19.1
unnamed: R15.1, R16.2, U4.1 (FB)
unnamed: J5.B5 (CC2), R20.2
unnamed: C33.1, R21.1, U7.31 (!RESET)
unnamed: C25.1, Q2.1 (G), R24.2, R25.2
unnamed: C24.2, D4.2 (A), Q1.1 (G), Q2.3 (D), R23.1
unnamed: D5.2 (A), R26.2
unnamed: JP2.2, R28.2
OUTL: C22.2, J2.4, J2.5
OUTR: C23.2, J2.3, J2.6
PWR_BTN: D4.1 (C), D5.1 (C), J4.6, TP11.TP
PWR_OFF: R25.1, TP10.TP, U$1.P$114 (GPIO2)
QSPI_SCLK: U2.52 (QSPI_SCLK), U8.6 (CLK)
QSPI_SD0: U2.53 (QSPI_SD0), U8.5 (DI(IO0))
QSPI_SD1: U2.55 (QSPI_SD1), U8.2 (DO(IO1))
QSPI_SD2: U2.54 (QSPI_SD2), U8.3 (!WP!(IO2))
QSPI_SD3: U2.51 (QSPI_SD3), U8.7 (!HOLD/RESET!(IO3))
QSPI_SS: R1.1, R3.2, U2.56 (QSPI_SS_N), U8.1 (!CS)
ROW0: SW_E.3, SW_E.4, SW_I.3, SW_I.4, SW_O.3, SW_O.4, SW_P.3, SW_P.4, SW_Q.3, SW_Q.4, SW_R.3, SW_R.4, SW_T.3, SW_T.4, SW_U.3, SW_U.4, SW_W.3, SW_W.4, SW_Y.3, SW_Y.4, U2.14 (GPIO11)
ROW1: SW_A.3, SW_A.4, SW_BSP.3, SW_BSP.4, SW_D.3, SW_D.4, SW_F.3, SW_F.4, SW_G.3, SW_G.4, SW_H.3, SW_H.4, SW_J.3, SW_J.4, SW_K.3, SW_K.4, SW_L.3, SW_L.4, SW_S.3, SW_S.4, U2.15 (GPIO12)
ROW2: SW_..3, SW_..4, SW_?.3, SW_?.4, SW_B.3, SW_B.4, SW_C.3, SW_C.4, SW_ENTER.3, SW_ENTER.4, SW_M.3, SW_M.4, SW_N.3, SW_N.4, SW_V.3, SW_V.4, SW_X.3, SW_X.4, SW_Z.3, SW_Z.4, U2.16 (GPIO13)
ROW3: SW_/.3, SW_/.4, SW_ALT.3, SW_ALT.4, SW_CMD.3, SW_CMD.4, SW_CTL.3, SW_CTL.4, SW_SHFT.3, SW_SHFT.4, SW_SP1.3, SW_SP1.4, SW_SP2.3, SW_SP2.4, SW_SYM.3, SW_SYM.4, SW_TAB.3, SW_TAB.4, SW_}.3, SW_}.4, U2.17 (GPIO14)
RP2040_USBT_N: R4.1, U2.46 (USB_DM)
RP2040_USBT_P: R5.2, U2.47 (USB_DP)
RP2040_USB_N: R4.2, U5.4 (D-)
RP2040_USB_P: R5.1, U5.3 (D+)
SCL: R8.1, TP5.TP, U2.39 (GPIO27/ADC1), U6.7 (SCL), U7.10 (SCL), U$1.P$43 (SCL0)
SDA: R7.1, TP6.TP, U2.38 (GPIO26/ADC0), U6.8 (SDA), U7.9 (SDA), U$1.P$42 (SDA0)
SD_CLK: J3.5 (CLK), U$1.P$127 (SD_CLK)
SD_CMD: J3.3 (CMD), U$1.P$128 (SD_CMD)
SD_DAT0: J3.7 (DAT0), U$1.P$125 (SD_DAT0)
SD_DAT1: J3.8 (DAT1), U$1.P$124 (SD_DAT1)
SD_DAT2: J3.1 (DAT2), U$1.P$131 (SD_DAT2)
SD_DAT3: J3.2 (CD/DAT3), U$1.P$130 (SD_DAT3)
SELECT: SELECT.1, SELECT.2, U2.12 (GPIO9)
SHT_DWN: R26.1, TP9.TP, U$1.P$113 (GPIO3)
SPI_CLK: J4.12, U$1.P$92 (GPIO11)
SPI_MISO: J4.14, U$1.P$95 (GPIO9)
SPI_MOSI: J4.13, U$1.P$97 (GPIO10)
SPKM: SPEAKER.M, U7.19 (SPKM), U7.23 (SPKM)
SPKP: SPEAKER.P, U7.22 (SPKP), U7.26 (SPKP)
START: START.1, START.2, U2.11 (GPIO8)
SW: L1.2, U4.5 (SW)
SWCLK: U2.24 (SWCLK)
SWDIO: U2.25 (SWDIO)
USB_N: J5.A7 (DN1), J5.B7 (DN2), U5.8 (HSD2-)
USB_P: J5.A6 (DP1), J5.B6 (DP2), U5.9 (HSD2+)
USB_SELECT: JP2.1, R27.1, U5.2 (SEL)
VBAT: BAT.1, C20.1, C21.1, U3.2 (BAT), U6.2 (CELL), U6.3 (VDD)
VBUS: C15.1, J5.A4_B9 (VBUS), J5.B4_A9 (VBUS), R28.1, U3.10 (IN)
VSYS: C16.1, C24.1, D1.A, D2.A, Q1.2 (S), R23.2, TP8.TP, U3.1 (SYS)
VSYS_ON: C17.1, L1.1, Q1.3 (D), R11.2, TP7.TP, U4.3 (VIN)
XIN: C2.2, U2.20 (XIN), Y1.1
XOUT: R2.2, U2.21 (XOUT)

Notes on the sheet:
BQ25185 (charging) TPS61023 (boost) MAX17048 (gauge)
Place closer to pin 44 - 45

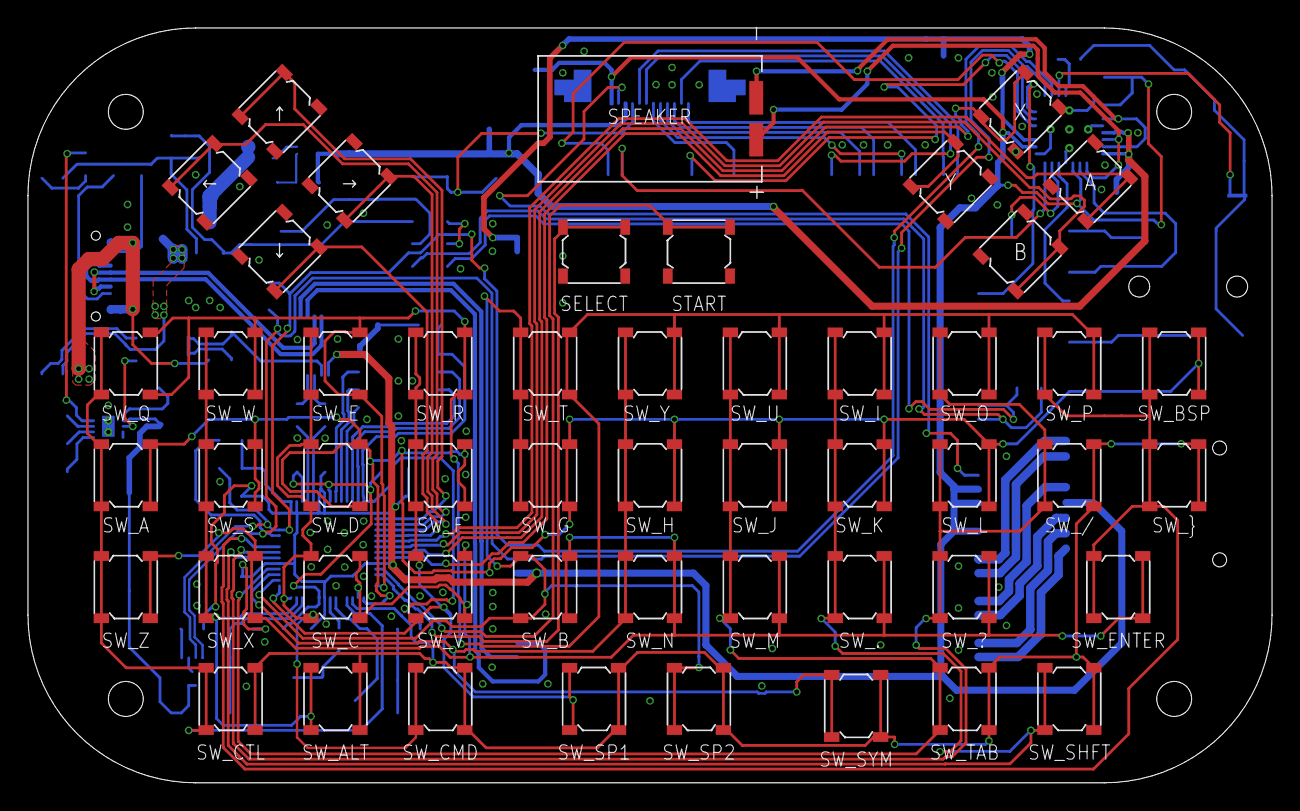
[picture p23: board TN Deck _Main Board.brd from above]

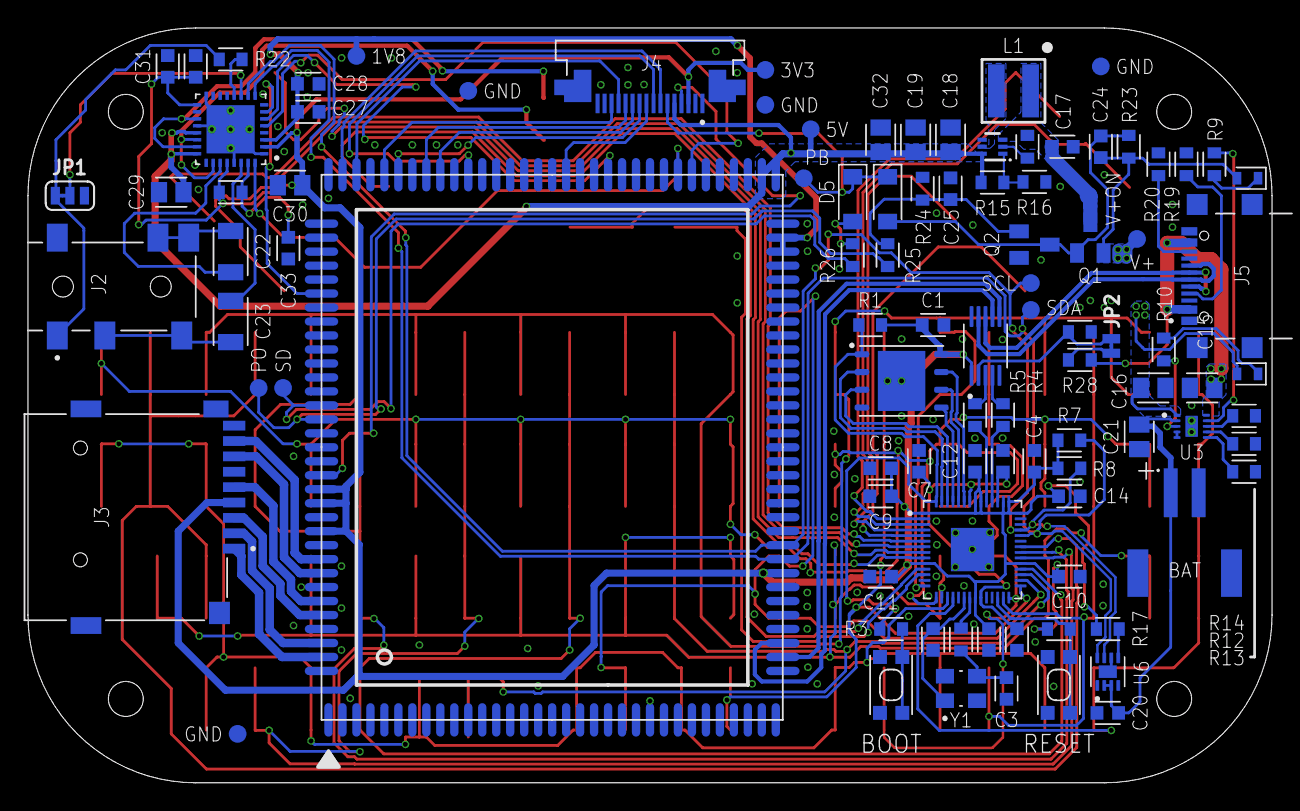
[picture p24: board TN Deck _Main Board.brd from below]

Board: 2 copper layers, 89.0 x 54.0 mm, 150 parts (99 on the bottom side), 104 nets.

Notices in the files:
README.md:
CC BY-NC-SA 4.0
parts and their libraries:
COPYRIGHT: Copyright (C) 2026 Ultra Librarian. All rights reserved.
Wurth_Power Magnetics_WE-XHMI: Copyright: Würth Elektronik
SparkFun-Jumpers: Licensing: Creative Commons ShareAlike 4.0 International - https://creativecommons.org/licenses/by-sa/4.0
